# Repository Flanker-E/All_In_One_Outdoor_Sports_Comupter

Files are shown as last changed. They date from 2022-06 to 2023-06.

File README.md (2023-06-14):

# All-in-one Outdoor Sports Comupter







This is Team 15's final project git repository for EECS 473: Advanced Embedded Systems. 

The title of our project is **All-in-one Outdoor Sports Comupter**

The team members include: Zhewei Ye, Zheyuan Wu, Yuantao Bai, Yifan Yang, Yidong Zhen, Yuxin Wang.

## 🌟 Expo
Poster of the project

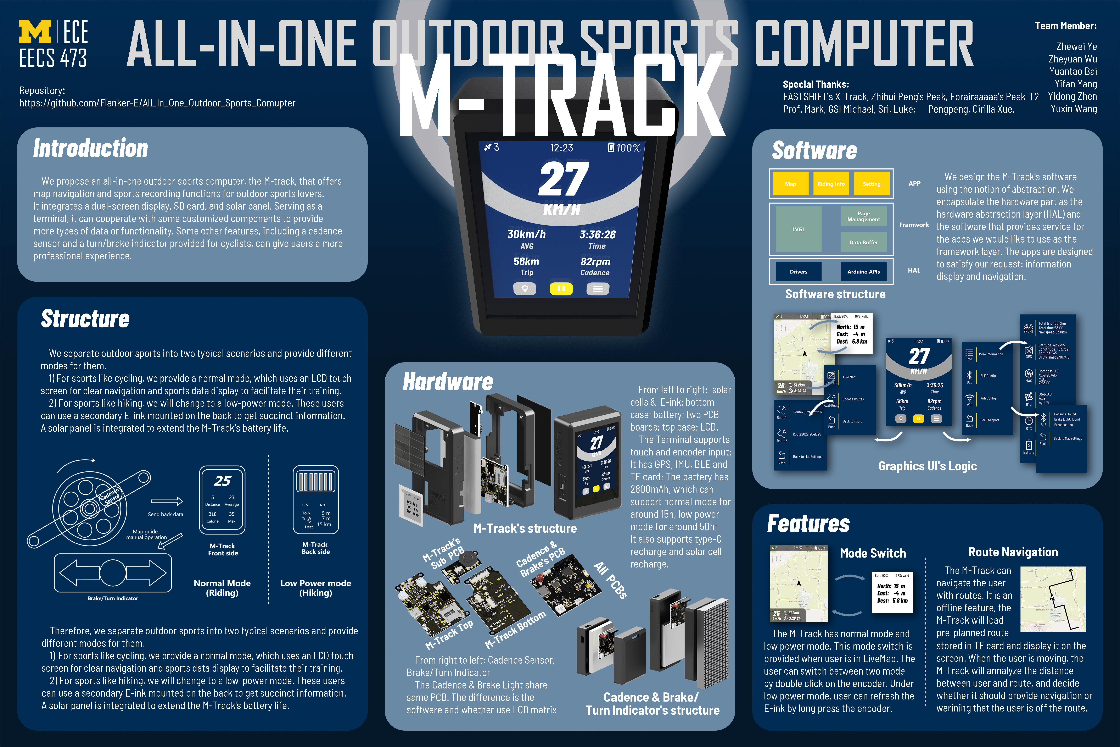
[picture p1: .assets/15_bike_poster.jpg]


## 🏅 Acknowledgement
Thanks for the great work: 
+ [**X-Track**](https://github.com/FASTSHIFT/X-TRACK)
+ [**Peak**](https://github.com/peng-zhihui/Peak)
+ [**Peak-T2**](https://gitee.com/forairaaaaa/peak-t2/tree/master/1.Hardware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)

## ⚙️ Firmware compile using PIO
Open project with Vscode, wait for PlatformIO to configure the project.  

### configure lvgl/lv_conf.h  
copy from lv_conf_template.h and change name to lv_conf.h  
line 15 change to -> #if 1 
line 52 change to -> #define LV_MEM_SIZE (38U * 1024U)          /*[bytes]*/  
line 88 change to -> #define LV_TICK_CUSTOM 1  
line 114 change to -> #define LV_SHADOW_CACHE_SIZE 50  
line 174 change to -> #define LV_USE_LOG 1  
line 210 change to -> #define LV_USE_ASSERT_STYLE 1  
line 245 change to -> #define LV_SPRINTF_USE_FLOAT 1  
line 306 change to -> #define LV_FONT_MONTSERRAT_10 1  
line 314 change to -> #define LV_FONT_MONTSERRAT_26 1  
line 348 change to -> #define LV_FONT_FMT_TXT_LARGE 1  
line 351 change to -> #define LV_USE_FONT_COMPRESSED 1  
line 526 change to -> #define LV_USE_THEME_BASIC 0  
line 529 change to -> #define LV_USE_THEME_MONO 0  

### using 7789V(PCB):  
#### configure TFT_eSPI/User_Setup.h  
uncomment line 45  
comment line 168-170  
comment line 205-210 and 223  
#### configure TFT_eSPI/User_Setup_select.h  
uncomment line 72 setup24_st7789.h  
#### configure TFT_eSPI/User_Setups/Setup24_ST7789.h  
uncomment line 10, enable TFT_RGB  
uncomment line 22-27, change TFT_CS to 9  
comment line 30-33  

### using IL9341(quick proto):   
#### configure TFT_eSPI/User_Setup.h  
comment line 168-170  
uncomment line 205-210 and 223  

## How to get simulator work on Windows
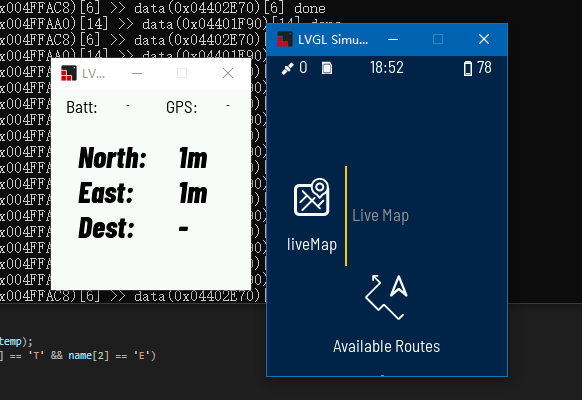
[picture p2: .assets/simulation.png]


Clone project.  
Open project with Vscode, wait for PlatformIO to configure the project.  
Download Visual Studio 2019.(can't work with 2022)  
Install module: C++ desktop(click on MSVC v142-VS 2019) and .NET desktop.  
Open the .sln file, select x86 Debug and run.  
Then the simulator should can work.  

## How to get simulator work on MacOS
todo 
some basic function don't work under Mac c++ env.

## Software Part Understanding
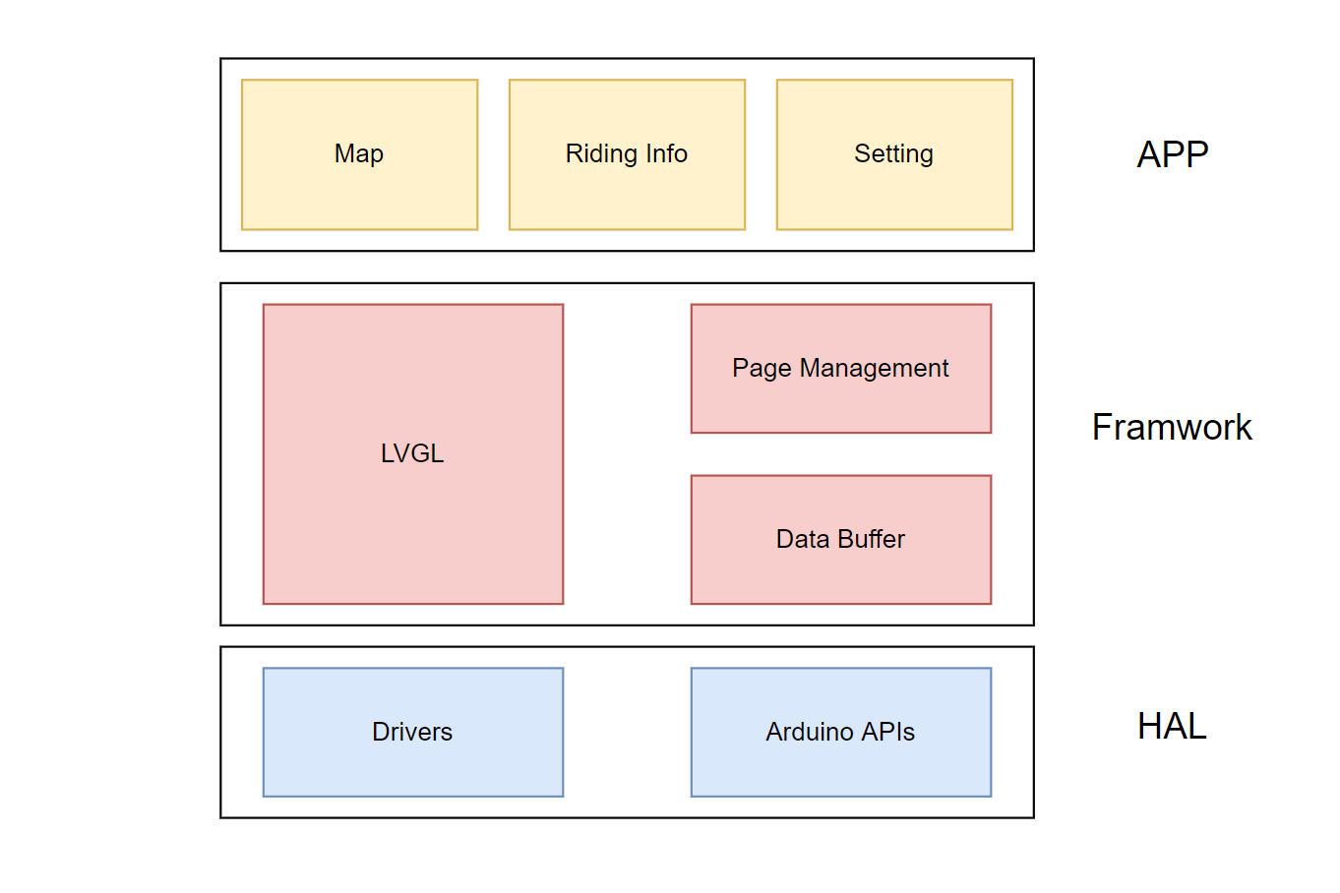
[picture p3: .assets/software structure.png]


### Software Init Pipeline
Setup:  
* HAL_init;  
    * buzz: thread(tailored in this project)  
*	Port_Init //LCD  
    * Tft object setup, binding with LVGL  
    * Create FreeRTOS task  
*	App_init  
    * Init data buffer, lv clear, init resourse, create apps, bind service  

Loop:  
*	HAL_update  

After that, the FreeRTOS will periodically call lv_handler, which gives lvgl heart beat.  
The software structure and lvgl outside of FreeRTOS will listen from input and periodic timers to do its job.  

### Software Structure (explaination on content)
#### FreeRTOS
* Task1: lvgl update  
* Task2: pending: HAL update 
* Task3: pending: switch between LCD and Eink 
plan : using state machine to control the shift between normal mode and low power mode.  
#### Data Buffer:
Namespace DataProc:  

class:  
Account:   
all account connect to one data center. Using an id to distinguish.   
Having a general pingpong buffer and a specified user data pointer.  
Using commit to get data and use publish to notify all subscriber with new data.  
Can data can be pull from subscriber.  
Timer’s utility? Cmd utility?  

DataCenter:  
Provide find specific account utility.  
Store accounts using account pool, which is a vector.  

Pingpong buffer:  

    void* buffer[2];
        volatile uint8_t writeIndex;
        volatile uint8_t readIndex;
        volatile uint8_t readAvaliable[2];
          
readidx=0 or 1. After read, set avai to 0.  
Write: can not be the same with read. Write to another slot and set its availability to 1.  

#### App
**AppFactory:** public inherited from PageFactory  
Provide createpage check function. Check whether “create a page named xx” is legal. Then return the page object  

**PageManager:** manage pages. Install, register, push&pop of page stack, page switch and the other stuff.  
Organized the page-switching logic!  
Install of page: init page, assign some information of this page.  
Register of page: assign PM’s this pointer, assign page name to itself (?), pushback in pagepool  

**Page stack and page pool:**  
Page stack is used to store the sequence of appearance of pages. Page pool is used to check whether a page is registered or not.  

The app will show after it is pushed into the stack by calling “SwitchTo”  
Switch to: detect and copy stash into the target page.  

The PM will raise StateUpdate to check the state and call corresponding functions in pages (state machine)  

**App uses the MVC framework:**  
[Basic concept reference](https://www.zhihu.com/question/27897315)  
[For detailed information and iOS ViewController: ](https://www.jianshu.com/p/caaa173071f3)  
[Difference from MVP: ](http://c.biancheng.net/view/7743.html) Then you will notice that there are differences in the definition of MVC.

Implemented functionality for page scheduling (lifecycle).

Porting: Add pages to the pool using "push" and go back to the previous page using "pop".

Ensure that the hardware is initialized to prevent SystemInfo from referencing a null pointer.

**Add other pages:**

Page: Interface functionality, including creation, display, loading, etc.

PageView: Implementation of functionalities such as creation, grouping, etc.

PageModel: Functionality for data interaction, such as reading data and updating.

onBtnClicked called by onEvent. onEvent is a callback function, which is attached to events by lv_obj_add_event_cb In onEvent

The onEvent will call different functions based on the event code.  

The information updates of map and dialplate are done by lv_timer  

#### Button and Lvgl
Encoder_Init provide: hardware interrupt when a pin changed, attach encoder with buttonEvent  
Bind encoder in the Encoder_Init only provide long press power off feature(disable encoder difference calc)  
Encoder_Update will call ButtonEvent’s EventMonitor, which judge the state of press. This can determin whether device should be power off.  

Lvgl determines press event using the encoder_read call-back function. It reads diff and state from encoder driver.  
#### Map
Using Microsoft Tiled map system: different scale, different image.   
Which uses scale number to calculate the crop of an image.  

Namespace page  
Class livemap :pagebase  

MapConv mapConv;  
TileConv tileConv;  

When things are being updated. Enter or outside from map?
Using lv_poly_line to record track line

Observation: the map will exit when button is pressed(before release)
#### Resource Pool
Import fonts, label images
## 🎬 Pictures and Documentation
+ Project Document: [**[PDF]**](https://github.com/Flanker-E/All_In_One_Outdoor_Sports_Comupter/blob/main/.assets/Team15_473F22_report.docx.pdf)

+ Route recording and navigation: Yellow is recorded route and blue is navigation route.

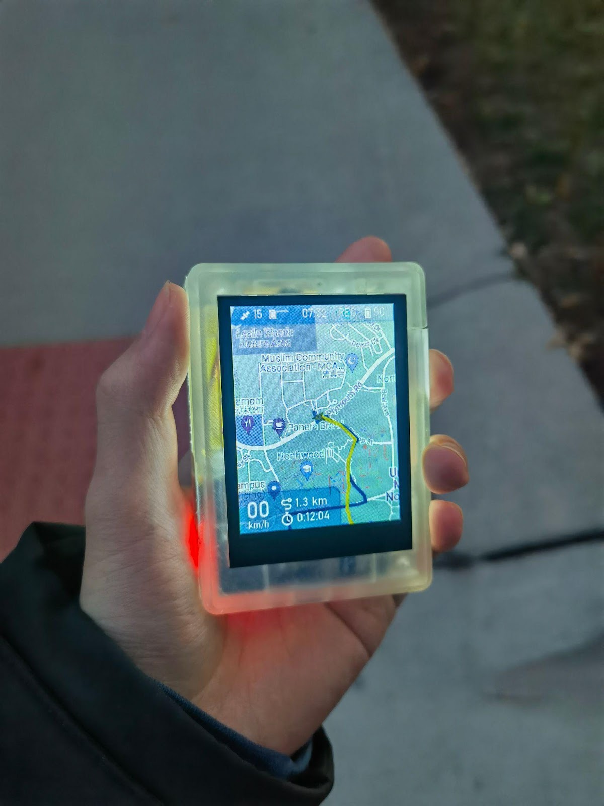
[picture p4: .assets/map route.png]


+ Front view
  
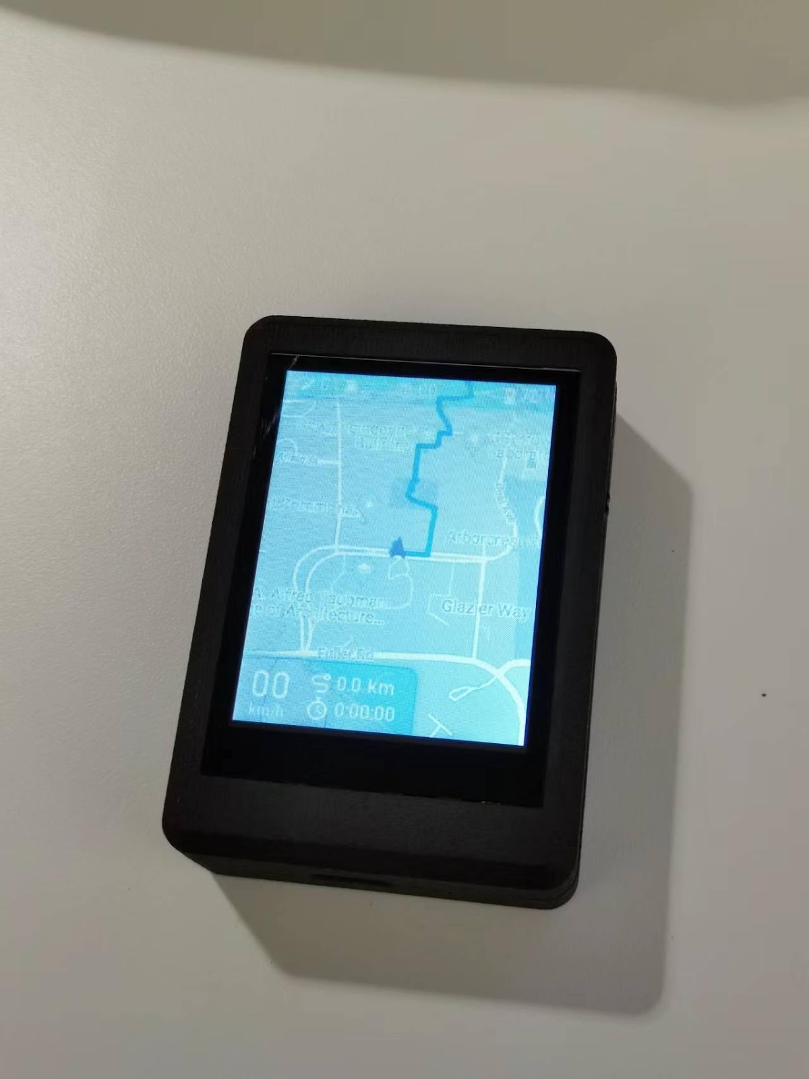
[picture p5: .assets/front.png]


+ Back view
  
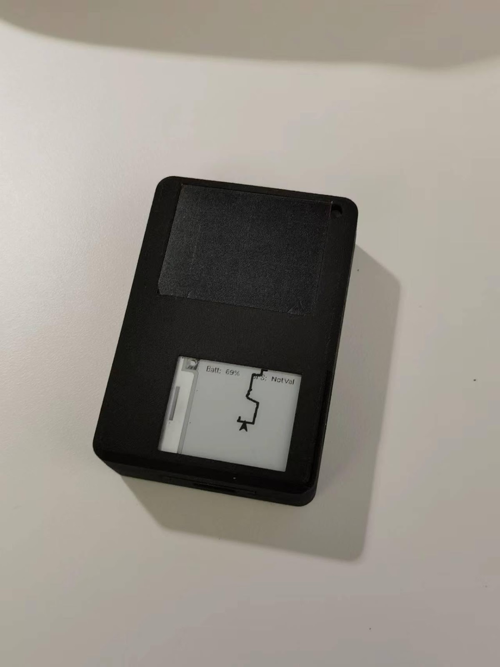
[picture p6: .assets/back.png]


+ Overall assembly rendering.

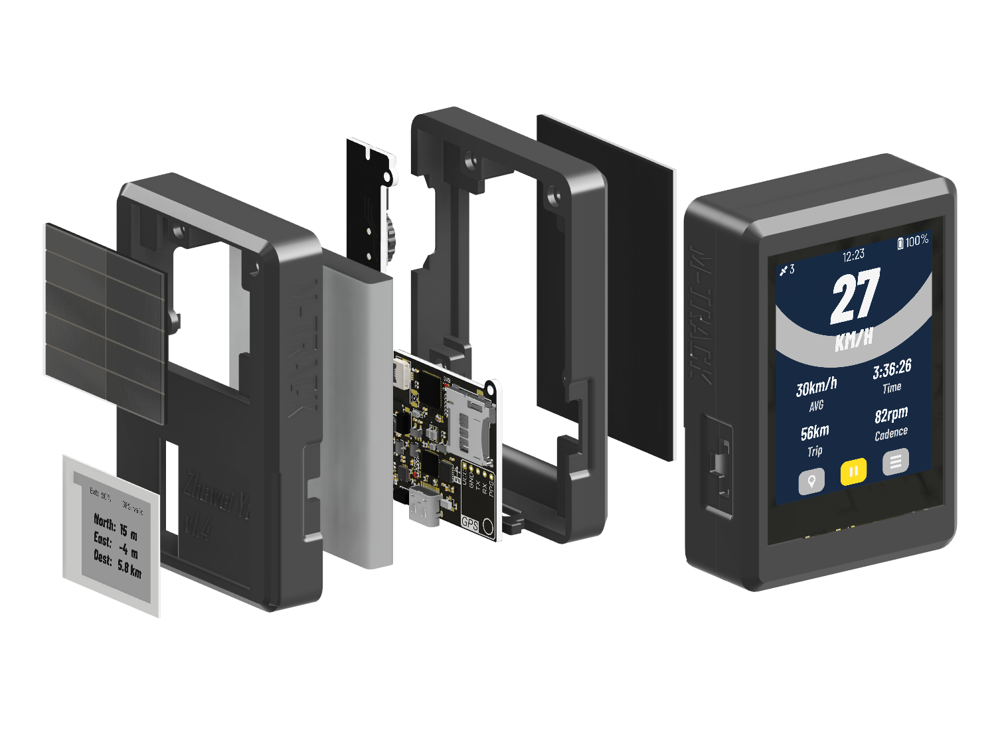
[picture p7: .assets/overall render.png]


+ inner rendering
  
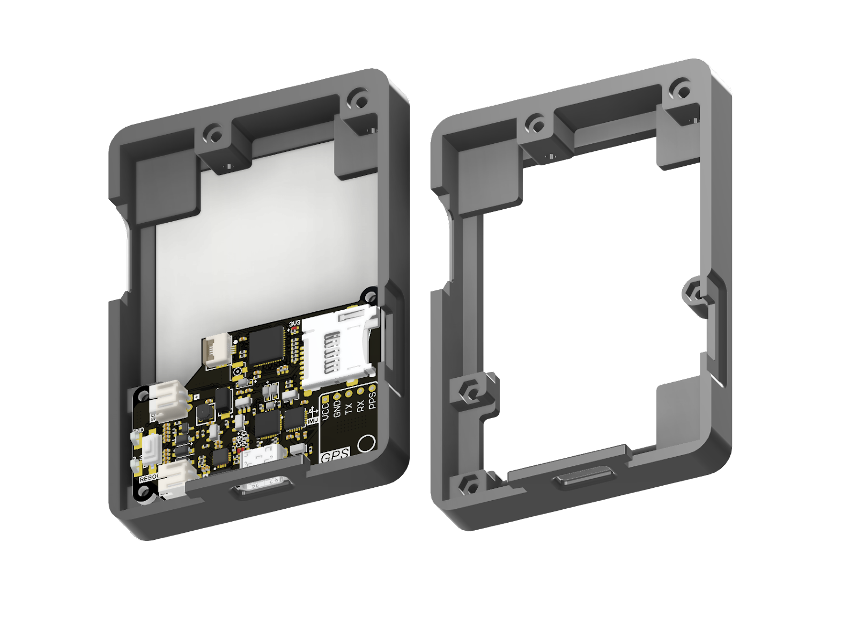
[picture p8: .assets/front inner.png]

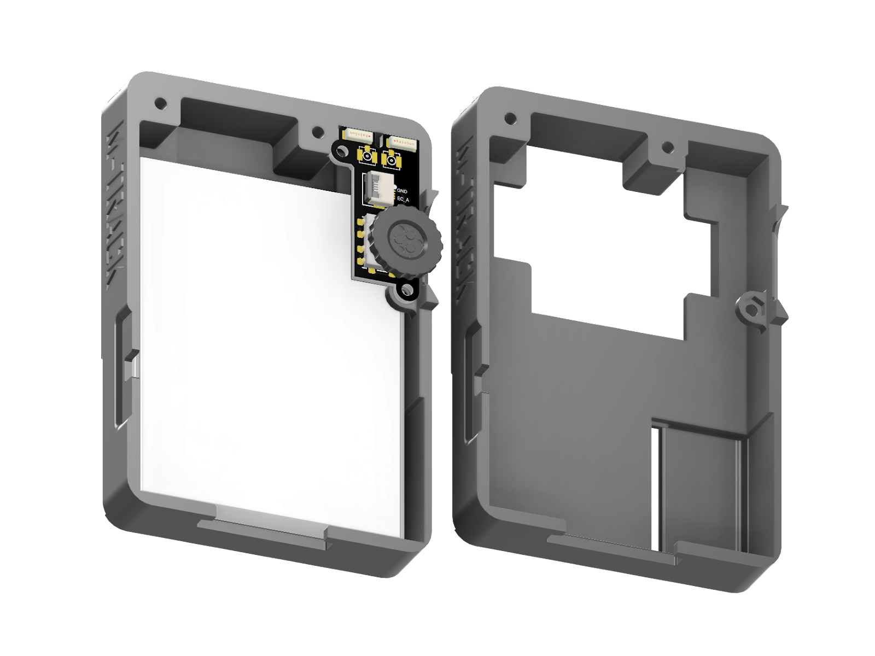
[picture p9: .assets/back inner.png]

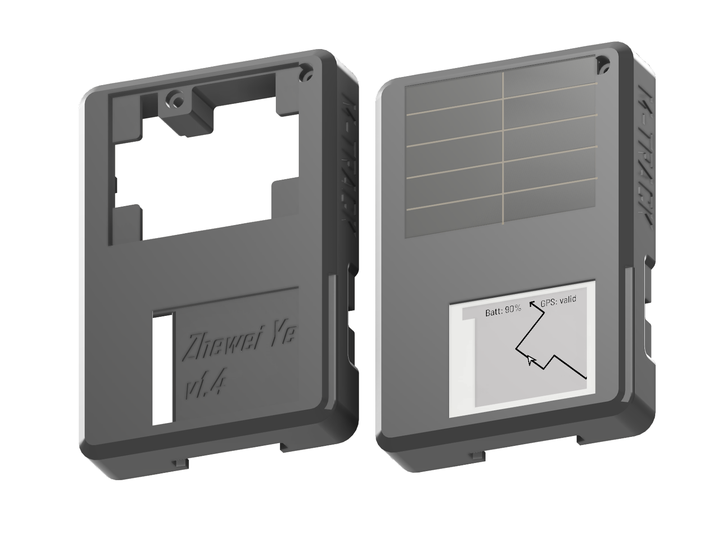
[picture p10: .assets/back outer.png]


+ PCB rendering and photo
  
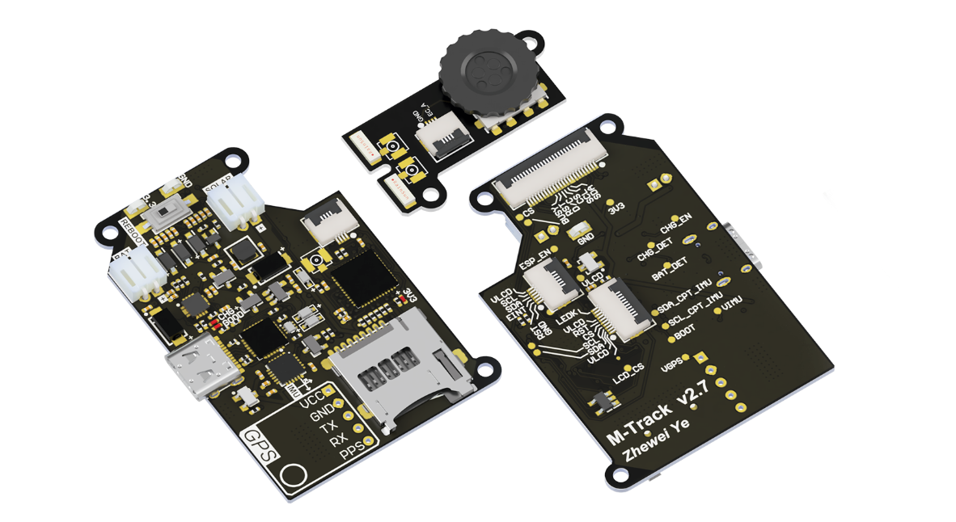
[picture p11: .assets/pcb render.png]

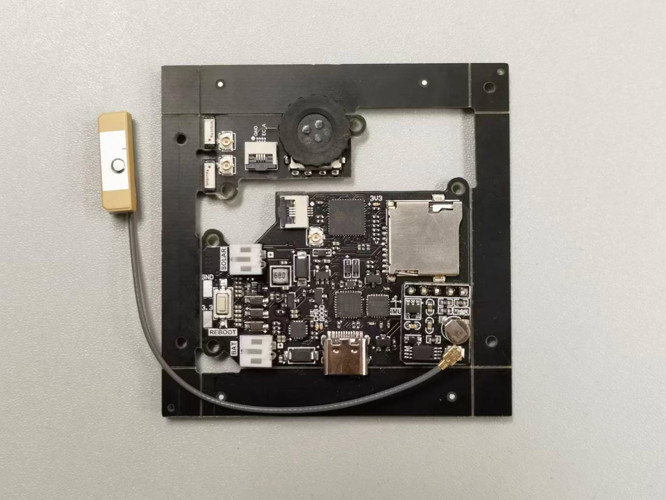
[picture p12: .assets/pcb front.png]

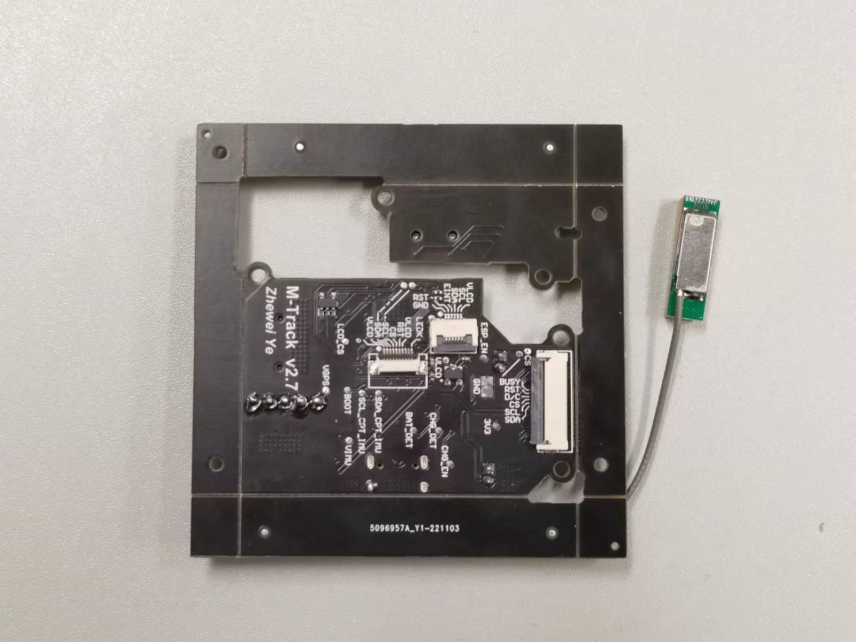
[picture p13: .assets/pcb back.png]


## 📫 Contact

+ Zhewei Ye, Email: yezhewei@umich.edu
+ Zheyuan Wu, Email: wuzy@umich.edu
+ Yuantao Bai, Email: yuantaob@umich.edu
+ Yifan Yang, Email: yifanyan@umich.edu
+ Yidong Zhen, Email: ydzhen@umich.edu
+ Yuxin Wang, Email: yuxinece@umich.edu
  
## 📌 Project Changelog
20220617 demo widges, run in FreeRTOS, with semaphor. Record before adding X-track page management and display port.  
20220624 touchpad on peak pages.  
20220626 sysinfo works. battery label update error.  
20220629 X-track pages, simulator, touchpad problem.  
20220928 sync using new machine.  
20221004 update hardware design.  
20221102 PCB v2.7 =>Fab  
20221110 case 3D modeling v1.3  
20221116 driver switch between LCD and EINK  
20221120 case 3D modeling v1.4, revision for PCB v2.7  
20221122 incorporate encoder and touch screen  
20221123 solved the switch between LCD and Eink  
20221127 adding settings page  
20221128 design settings items' icon  
20221202 fix encoder click logic  
20221205 poster stuff, tf card and map load  
20221206 time issure, positioning offset, route recording enable  
20221207 available route read and selection UI

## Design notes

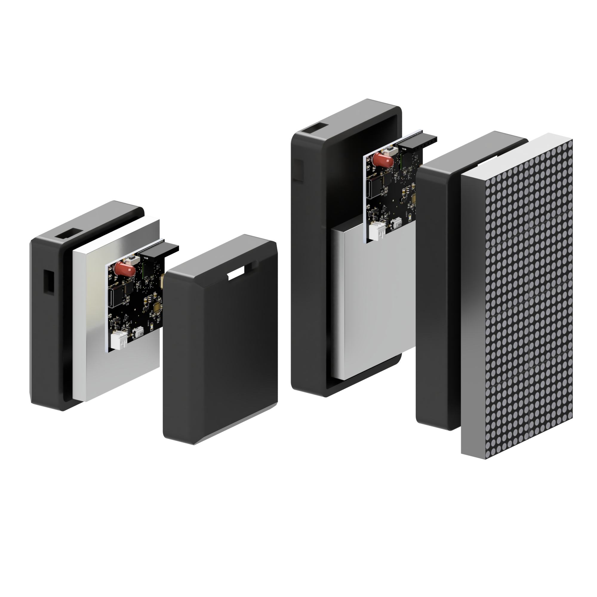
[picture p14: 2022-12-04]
Poster/Cadence_Brake.PNG

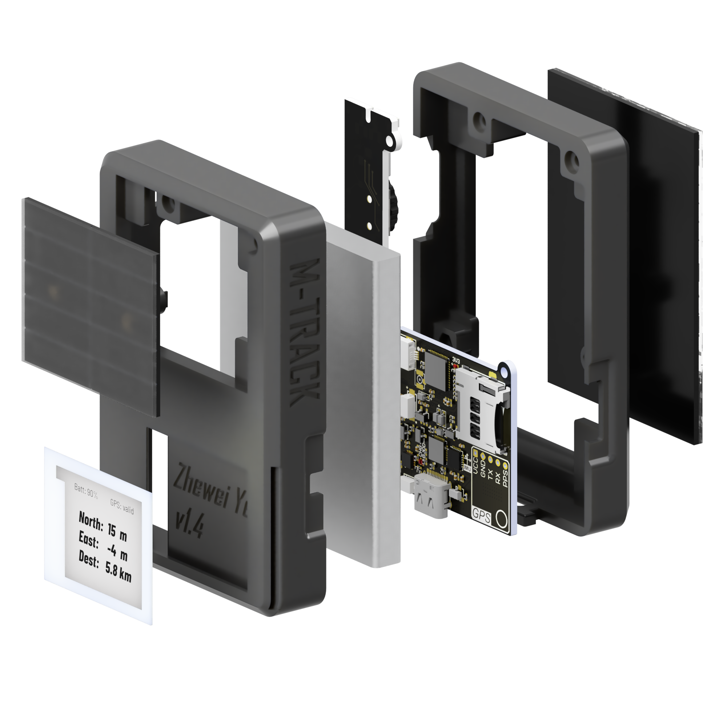
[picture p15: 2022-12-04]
Poster/M_TRACK_transpatent.png

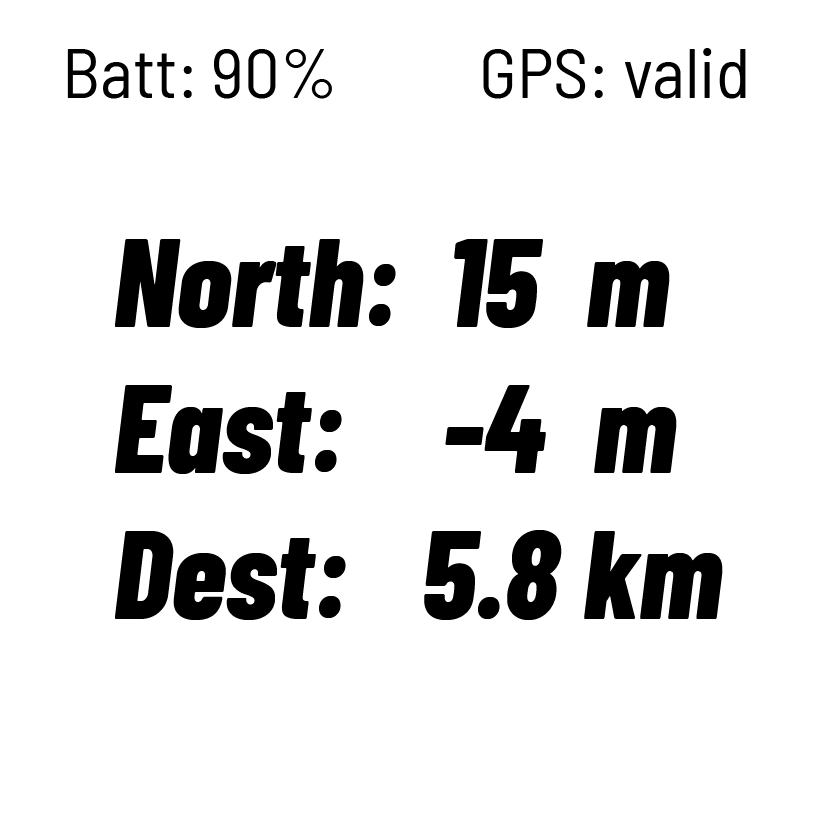
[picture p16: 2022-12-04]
Poster/E_ink.png

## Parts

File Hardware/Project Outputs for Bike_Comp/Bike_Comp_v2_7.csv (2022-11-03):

Comment | Description | Designator | Footprint | LibRef | Quantity
AN2051-245 | footprint: 2051 | A1, A2 | ANT-Rainsun-AN5120 | ANT-Rainsun-AP5120 | 2
ATGM336H Module | ATGM336H Module | AT1 | PCBComponent_1 | ATGM336H Module | 1
0.1uF | Capacitor | C1, C4, C6, C11, C13, C14, C16 | CAP_0402 | 电容-0402 | 7
10uF | Capacitor | C2, C5, C7, C8, C9, C17, C18, C19, C20 | CAP_0402 | 电容-0402 | 9
1uF | Capacitor | C10, C21, C25, C26, C27, C32 | CAP_0402 | 电容-0402 | 6
10nF | Capacitor | C12 | CAP_0402 | 电容-0402 | 1
2.2nF | Capacitor | C15 | CAP_0402 | 电容-0402 | 1
4.7uF | Capacitor | C22, C23, C24, C28, C29, C30, C31 | CAP_0402 | 电容-0402 | 7
FPC05006-09200 | 下接6p | CT1 | FPC0.5-WT-6P | CTP | 1
B5819W | 40V | D1, D2, D3 | SOD-323 | 二极管-5819W | 3
SK34A | GOOD_ARK Schottky Diode | D4, D6 | SMA | SK34AFL-TP | 2
LTST-C281KGKT | GREEN_LED | D5, D8 | LED_0402_RED | LED_0402 | 2
16-213/SDRC/S530-A3/TR8 | RED_LED | D7 | LED_0402_RED | LED_0402 | 1
MBR0530 | Diode | D9, D10, D11 | SOD3716X135N | MBR0530 | 3
FPC05024-17205 | 上接24p | EINK1 | FPC0.5-WT-24P | EINK | 1
BQ24074RGTR | Integrated Circuit | IC1 | QFN50P300X300X100-17N-D | BQ24074RGTR | 1
74LVC1G04W5-7 | Integrated Circuit | IC2 | SOT95P285X140-5N | 74LVC1G04W5-7 | 1
IPEX-4 | Socket, Plug | J1, J2, P2 | COAXIAL/SMD/CON/V/I-PEX/W08-5801 | Socket, Plug | 3
68uH ±20% | Magnetic-Core Inductor | L1 | SWPA3015 | Inductor Iron | 1
0.5-10P上接 | 上接10p | LC1 | FPC0.5-WT-10P | LCD | 1
BAT_CON | PH2.0-2P-LT | P1 | PH2.0-W-2P | Header 2 | 1
C191195 | Header, 4-Pin | P3, P4 | FPC0.5-WT-4P | Header 4 | 2
SOLAR_CON | PH2.0-2P-LT | P6 | PH2.0-W-2P | Header 2 | 1
AO3401A | P-MOS | Q1, Q6, Q8 | SOT23-3 | AO3401A | 3
AO3400A | N-MOS | Q2, Q4 | SOT23-3 | AO3400A | 2
EMX1T2R |  | Q3 | SOT563-6 | BC847BVC-7 | 1
Si1308EDL-T1-GE3 | MOSFET (N-Channel) | Q9 | SOT65P210X110-3N | Si1308EDL-T1-GE3 | 1
10K | Resistor | R1, R8, R11, R13, R17, R18, R19, R20, R21, R22, R23, R25, R26, R27, R32, R34, R35, R36 | RES_0402 | 电阻-0402 | 18
100K | Resistor | R2, R4, R28, R30 | RES_0402 | 电阻-0402 | 4
20K | Resistor | R3, R7 | RES_0402 | 电阻-0402 | 2
0R | Resistor | R5, R24, R38, R39 | RES_0402 | 电阻-0402 | 4
200R | Resistor | R6 | RES_0402 | 电阻-0402 | 1
12K | Resistor | R9, R12 | RES_0402 | 电阻-0402 | 2
1K | Resistor | R10, R31 | RES_0402 | 电阻-0402 | 2
5.1K | Resistor | R14, R16 | RES_0402 | 电阻-0402 | 2
10R | Resistor | R15 | RES_0402 | 电阻-0402 | 1
TSA363G25-250B | Single-Pole, Single-Throw Switch | S1 | SW SMD-3*6*2.5 | SW-SPST | 1
SIQ-02FVS3 | Rotary Encoder | SW1 | SIQ-02FVS3 | Rotary Encoder | 1
TF-012D | 8脚自弹 | TF1 | TF-SOCKET | TF卡座 | 1
TP |  | TP1, TP3, TP10 | TP_SMD | TP | 3
TP |  | TP2, TP4, TP5, TP6, TP7, TP8, TP9, TP12, TP14, TP15, TP16, TP17, TP18, TP19, TP20, TP22, TP23 | TEST 1 | TP | 17
ME6215C33M5G | LDO module changed, BYPASS now is NC | U1 | SOT23-5 | LP2992 | 1
CP2102 | USB转TTL | U2 | QFN-28 | CP2102 | 1
ESP32-PICO-D4 |  | U4 | QFN-48_7X7 | ESP32-PICO | 1
MPU6050 | 六轴传感器 | U5 | QFN-24 | MPU6050 | 1
TYPE-611-T3 | 16pin | USB1 | Type-C-TOP | USB-Type-C-TOP | 1

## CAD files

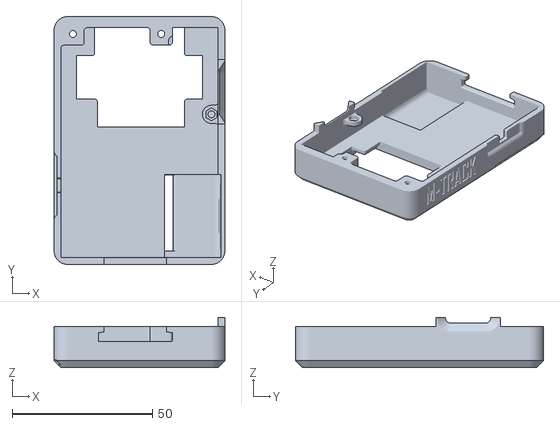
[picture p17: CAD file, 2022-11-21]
Model/M_Track_back_v1_4.stl
61.0 x 88.5 x 18.0

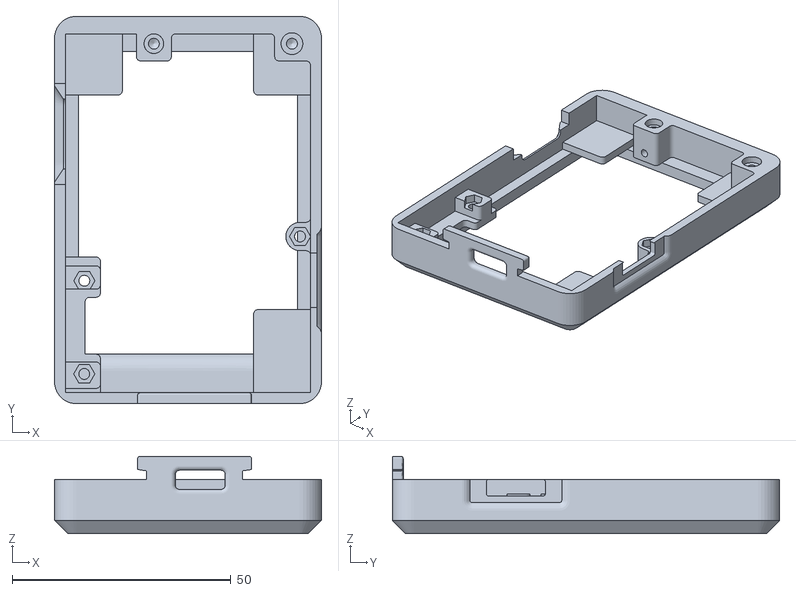
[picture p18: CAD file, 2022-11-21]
Model/M_Track_front_v1_4.stl
61.0 x 88.5 x 17.6

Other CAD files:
Model/back_v1_4.f3d
Model/front_v1_4.f3d

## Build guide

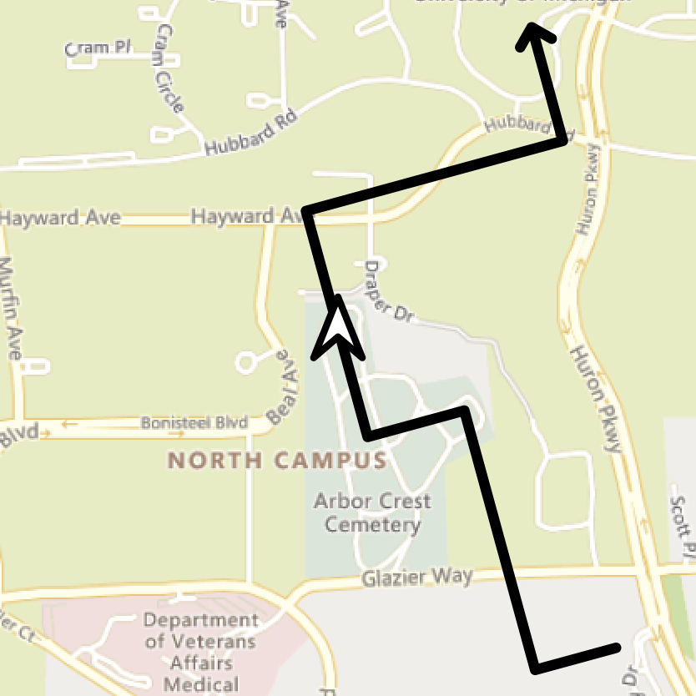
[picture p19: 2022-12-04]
Poster/RouteGuide_ 1.png

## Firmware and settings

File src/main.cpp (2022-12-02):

// #include <lv_demos.h>
// #include <TFT_eSPI.h>
#include "Port/Display.h"
#include "HAL/HAL.h"
#include "App/App.h"


// #include "TouchScreen.h"

void setup()
{
  //  File f = SPIFFS.open(CALIBRATION_FILE, "r");
    // Serial.begin( 115200 ); /* prepare for possible serial debug */

    // String LVGL_Arduino = "Hello Arduino! ";
    // LVGL_Arduino += String('V') + lv_version_major() + "." + lv_version_minor() + "." + lv_version_patch();

    // Serial.println( LVGL_Arduino );
    // Serial.println( "I am LVGL_Arduino" );


    HAL::HAL_Init();
    Serial.println( "HAL Init" );
    Port_Init();
    // To_Eink_Port();

    // To_LCD_Port();
    // Serial.printf( "maintest:%d\n",test );
    Serial.println( "Port Init" );

    App_Init();

    Serial.println( "Setup done" );
}

void loop()
{
  HAL::HAL_Update();
    // xTaskNotifyGive(handleTaskLvgl);
    // lv_timer_handler(); /* let the GUI do its work */
    // lv_tick_inc(5);
    delay( 20 );
}


  
    /*
  Example animated analogue meters using a ILI9341 TFT LCD screen

  Needs Font 2 (also Font 4 if using large scale label)

  Make sure all the display driver and pin comnenctions are correct by
  editting the User_Setup.h file in the TFT_eSPI library folder.

  #########################################################################
  ###### DON'T FORGET TO UPDATE THE User_Setup.h FILE IN THE LIBRARY ######
  #########################################################################
*/
// #include "FS.h"

// #include <SPI.h>
// #include <TFT_eSPI.h>      // Hardware-specific library

// TFT_eSPI tft = TFT_eSPI(); // Invoke custom library

// // This is the file name used to store the calibration data
// // You can change this to create new calibration files.
// // The SPIFFS file name must start with "/".
// #define CALIBRATION_FILE "/TouchCalData1"

// // Set REPEAT_CAL to true instead of false to run calibration
// // again, otherwise it will only be done once.
// // Repeat calibration if you change the screen rotation.
// #define REPEAT_CAL false

// // Keypad start position, key sizes and spacing
// #define KEY_X 40 // Centre of key
// #define KEY_Y 96
// #define KEY_W 62 // Width and height
// #define KEY_H 30
// #define KEY_SPACING_X 18 // X and Y gap
// #define KEY_SPACING_Y 20
// #define KEY_TEXTSIZE 1   // Font size multiplier

// // Using two fonts since numbers are nice when bold
// #define LABEL1_FONT &FreeSansOblique12pt7b // Key label font 1
// #define LABEL2_FONT &FreeSansBold12pt7b    // Key label font 2

// // Numeric display box size and location
// #define DISP_X 1
// #define DISP_Y 10
// #define DISP_W 238
// #define DISP_H 50
// #define DISP_TSIZE 3
// #define DISP_TCOLOR TFT_CYAN

// // Number length, buffer for storing it and character index
// #define NUM_LEN 12
// char numberBuffer[NUM_LEN + 1] = "";
// uint8_t numberIndex = 0;

// // We have a status line for messages
// #define STATUS_X 120 // Centred on this
// #define STATUS_Y 65

// // Create 15 keys for the keypad
// char keyLabel[15][5] = {"New", "Del", "Send", "1", "2", "3", "4", "5", "6", "7", "8", "9", ".", "0", "#" };
// uint16_t keyColor[15] = {TFT_RED, TFT_DARKGREY, TFT_DARKGREEN,
//                          TFT_BLUE, TFT_BLUE, TFT_BLUE,
//                          TFT_BLUE, TFT_BLUE, TFT_BLUE,
//                          TFT_BLUE, TFT_BLUE, TFT_BLUE,
//                          TFT_BLUE, TFT_BLUE, TFT_BLUE
//                         };

// // Invoke the TFT_eSPI button class and create all the button objects
// TFT_eSPI_Button key[15];

// //------------------------------------------------------------------------------------------
// //------------------------------------------------------------------------------------------

// void drawKeypad()
// {
//   // Draw the keys
//   for (uint8_t row = 0; row < 5; row++) {
//     for (uint8_t col = 0; col < 3; col++) {
//       uint8_t b = col + row * 3;

//       if (b < 3) tft.setFreeFont(LABEL1_FONT);
//       else tft.setFreeFont(LABEL2_FONT);

//       key[b].initButton(&tft, KEY_X + col * (KEY_W + KEY_SPACING_X),
//                         KEY_Y + row * (KEY_H + KEY_SPACING_Y), // x, y, w, h, outline, fill, text
//                         KEY_W, KEY_H, TFT_WHITE, keyColor[b], TFT_WHITE,
//                         keyLabel[b], KEY_TEXTSIZE);
//       key[b].drawButton();
//     }
//   }
// }

// //------------------------------------------------------------------------------------------

// void touch_calibrate()
// {
//   uint16_t calData[5];
//   uint8_t calDataOK = 0;

//   // check file system exists
//   if (!SPIFFS.begin()) {
//     Serial.println("Formating file system");
//     SPIFFS.format();
//     SPIFFS.begin();
//   }

//   // check if calibration file exists and size is correct
//   if (SPIFFS.exists(CALIBRATION_FILE)) {
//     if (REPEAT_CAL)
//     {
//       // Delete if we want to re-calibrate
//       SPIFFS.remove(CALIBRATION_FILE);
//     }
//     else
//     {
//       File f = SPIFFS.open(CALIBRATION_FILE, "r");
//       if (f) {
//         if (f.readBytes((char *)calData, 14) == 14)
//           calDataOK = 1;
//         f.close();
//       }
//     }
//   }

//   if (calDataOK && !REPEAT_CAL) {
//     // calibration data valid
//     tft.setTouch(calData);
//   } else {
//     // data not valid so recalibrate
//     tft.fillScreen(TFT_BLACK);
//     tft.setCursor(20, 0);
//     tft.setTextFont(2);
//     tft.setTextSize(1);
//     tft.setTextColor(TFT_WHITE, TFT_BLACK);

//     tft.println("Touch corners as indicated");

//     tft.setTextFont(1);
//     tft.println();

//     if (REPEAT_CAL) {
//       tft.setTextColor(TFT_RED, TFT_BLACK);
//       tft.println("Set REPEAT_CAL to false to stop this running again!");
//     }

//     tft.calibrateTouch(calData, TFT_MAGENTA, TFT_BLACK, 15);

//     tft.setTextColor(TFT_GREEN, TFT_BLACK);
//     tft.println("Calibration complete!");

//     // store data
//     File f = SPIFFS.open(CALIBRATION_FILE, "w");
//     if (f) {
//       f.write((const unsigned char *)calData, 14);
//       f.close();
//     }
//   }
// }

// //------------------------------------------------------------------------------------------

// // Print something in the mini status bar
// void status(const char *msg) {
//   tft.setTextPadding(240);
//   //tft.setCursor(STATUS_X, STATUS_Y);
//   tft.setTextColor(TFT_WHITE, TFT_DARKGREY);
//   tft.setTextFont(0);
//   tft.setTextDatum(TC_DATUM);
//   tft.setTextSize(1);
//   tft.drawString(msg, STATUS_X, STATUS_Y);
// }

// void setup() {
//   // Use serial port
//   Serial.begin(115200);

//   // Initialise the TFT screen
//   tft.init();

//   // Set the rotation before we calibrate
//   tft.setRotation(0);

//   // Calibrate the touch screen and retrieve the scaling factors
//   touch_calibrate();

//   // Clear the screen
//   tft.fillScreen(TFT_BLACK);

//   // Draw keypad background
//   tft.fillRect(0, 0, 240, 320, TFT_DARKGREY);

//   // Draw number display area and frame
//   tft.fillRect(DISP_X, DISP_Y, DISP_W, DISP_H, TFT_BLACK);
//   tft.drawRect(DISP_X, DISP_Y, DISP_W, DISP_H, TFT_WHITE);

//   // Draw keypad
//   drawKeypad();
// }

// //------------------------------------------------------------------------------------------

// void loop(void) {
//   uint16_t t_x = 0, t_y = 0; // To store the touch coordinates

//   // Pressed will be set true is there is a valid touch on the screen
//   bool pressed = tft.getTouch(&t_x, &t_y);

//   // / Check if any key coordinate boxes contain the touch coordinates
//   for (uint8_t b = 0; b < 15; b++) {
//     if (pressed && key[b].contains(t_x, t_y)) {
//       key[b].press(true);  // tell the button it is pressed
//     } else {
//       key[b].press(false);  // tell the button it is NOT pressed
//     }
//   }

//   // Check if any key has changed state
//   for (uint8_t b = 0; b < 15; b++) {

//     if (b < 3) tft.setFreeFont(LABEL1_FONT);
//     else tft.setFreeFont(LABEL2_FONT);

//     if (key[b].justReleased()) key[b].drawButton();     // draw normal

//     if (key[b].justPressed()) {
//       key[b].drawButton(true);  // draw invert

//       // if a numberpad button, append the relevant # to the numberBuffer
//       if (b >= 3) {
//         if (numberIndex < NUM_LEN) {
//           numberBuffer[numberIndex] = keyLabel[b][0];
//           numberIndex++;
//           numberBuffer[numberIndex] = 0; // zero terminate
//         }
//         status(""); // Clear the old status
//       }

//       // Del button, so delete last char
//       if (b == 1) {
//         numberBuffer[numberIndex] = 0;
//         if (numberIndex > 0) {
//           numberIndex--;
//           numberBuffer[numberIndex] = 0;//' ';
//         }
//         status(""); // Clear the old status
//       }

//       if (b == 2) {
//         status("Sent value to serial port");
//         Serial.println(numberBuffer);
//       }
//       // we dont really check that the text field makes sense
//       // just try to call
//       if (b == 0) {
//         status("Value cleared");
//         numberIndex = 0; // Reset index to 0
//         numberBuffer[numberIndex] = 0; // Place null in buffer
//       }

//       // Update the number display field
//       tft.setTextDatum(TL_DATUM);        // Use top left corner as text coord datum
//       tft.setFreeFont(&FreeSans18pt7b);  // Choose a nicefont that fits box
//       tft.setTextColor(DISP_TCOLOR);     // Set the font colour

//       // Draw the string, the value returned is the width in pixels
//       int xwidth = tft.drawString(numberBuffer, DISP_X + 4, DISP_Y + 12);

//       // Now cover up the rest of the line up by drawing a black rectangle.  No flicker this way
//       // but it will not work with italic or oblique fonts due to character overlap.
//       tft.fillRect(DISP_X + 4 + xwidth, DISP_Y + 1, DISP_W - xwidth - 5, DISP_H - 2, TFT_BLACK);

//       delay(10); // UI debouncing
//     }
//   }
// }


/*
    Video: https://www.youtube.com/watch?v=oCMOYS71NIU
    Based on Neil Kolban example for IDF: https://github.com/nkolban/esp32-snippets/blob/master/cpp_utils/tests/BLE%20Tests/SampleNotify.cpp
    Ported to Arduino ESP32 by Evandro Copercini
   Create a BLE server that, once we receive a connection, will send periodic notifications.
   创建一个BLE服务器，一旦我们收到连接，将会周期性发送通知
   T使用步骤：
   1. 创建一个 BLE Server
   2. 创建一个 BLE Service
   3. 创建一个 BLE Characteristic
   4. 创建一个 BLE Descriptor
   5. 开始服务
   6. 开始广播
*/
// #include <Arduino.h>
// #include <BLEDevice.h>
// #include <BLEServer.h>
// #include <BLEUtils.h>
// #include <BLE2902.h>
// // #include "common.h"

// uint8_t txValue = 0;
// BLEServer *pServer = NULL;                   //BLEServer指针 pServer
// BLECharacteristic *pTxCharacteristic = NULL; //BLECharacteristic指针 pTxCharacteristic
// bool deviceConnected = false;                //本次连接状态
// bool oldDeviceConnected = false;             //上次连接状态

// // See the following for generating UUIDs: https://www.uuidgenerator.net/
// #define SERVICE_UUID "3edbfa93-d64b-43c0-9d3c-e7388d43cd2f" // UART service UUID
// #define CHARACTERISTIC_UUID_RX "b42546cf-eac9-4b06-9377-17d71468e337"
// #define CHARACTERISTIC_UUID_TX "89b8d897-1faa-4c1d-9237-2aaf3584484c"

// class MyServerCallbacks : public BLEServerCallbacks
// {
//     void onConnect(BLEServer *pServer)
//     {
//         deviceConnected = true;
//     };

//     void onDisconnect(BLEServer *pServer)
//     {
//         deviceConnected = false;
//     }
// };

// class MyCallbacks : public BLECharacteristicCallbacks
// {
//     void onWrite(BLECharacteristic *pCharacteristic)
//     {
//         std::string rxValue = pCharacteristic->getValue(); //接收信息

//         if (rxValue.length() > 0)
//         { //向串口输出收到的值
//             Serial.print("RX: ");
//             for (int i = 0; i < rxValue.length(); i++)
//                 Serial.print(rxValue[i]);
//             Serial.println();
//         }
//     }
// };

// void setup()
// {
//     Serial.begin(115200);

//     // 创建一个 BLE 设备
//     BLEDevice::init("UART_BLE");

//     // 创建一个 BLE 服务
//     pServer = BLEDevice::createServer();
//     pServer->setCallbacks(new MyServerCallbacks()); //设置回调
//     BLEService *pService = pServer->createService(SERVICE_UUID);

//     // 创建一个 BLE 特征
//     pTxCharacteristic = pService->createCharacteristic(CHARACTERISTIC_UUID_TX, BLECharacteristic::PROPERTY_NOTIFY);
//     pTxCharacteristic->addDescriptor(new BLE2902());
//     BLECharacteristic *pRxCharacteristic = pService->createCharacteristic(CHARACTERISTIC_UUID_RX, BLECharacteristic::PROPERTY_WRITE);
//     pRxCharacteristic->setCallbacks(new MyCallbacks()); //设置回调

//     pService->start();                  // 开始服务
//     pServer->getAdvertising()->start(); // 开始广播
//     Serial.println(" waiting for connection... ");
// }

// void loop()
// {
//     // deviceConnected 已连接
//     if (deviceConnected)
//     {
//         pTxCharacteristic->setValue(&txValue, 1); // 设置要发送的值为1
//         pTxCharacteristic->notify();              // 广播
//         txValue++;                                // 指针地址自加1
//         delay(2000);                              // 如果有太多包要发送，蓝牙会堵塞
//     }

//     // disconnecting  断开连接
//     if (!deviceConnected && oldDeviceConnected)
//     {
//         delay(500);                  // 留时间给蓝牙缓冲
//         pServer->startAdvertising(); // 重新广播
//         Serial.println(" begin broadcast ");
//         oldDeviceConnected = deviceConnected;
//     }

//     // connecting  正在连接
//     if (deviceConnected && !oldDeviceConnected)
//     {
//         // do stuff here on connecting
//         oldDeviceConnected = deviceConnected;
//     }
// }

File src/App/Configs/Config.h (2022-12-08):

#ifndef __CONFIG_H
#define __CONFIG_H

/*=========================
   Application configuration
 *=========================*/

#define CONFIG_SYSTEM_SAVE_FILE_PATH          "/SystemSave.json"
#define CONFIG_SYSTEM_SAVE_FILE_BACKUP_PATH   "/.SystemSaveBackup.json"
#define CONFIG_SYSTEM_LANGUAGE_DEFAULT        "en-GB"//{'e','n','-','G','B'}
#define CONFIG_SYSTEM_TIME_ZONE_DEFAULT      (-5) // GMT- 5, Ann Arbor
#define CONFIG_SYSTEM_SOUND_ENABLE_DEFAULT    false

#define CONFIG_WEIGHT_DEFAULT                 70 // kg

#define CONFIG_GPS_REFR_PERIOD                1000 // ms
#define CONFIG_GPS_LONGITUDE_DEFAULT          -83.7161   //Ann Arbor duder
#define CONFIG_GPS_LATITUDE_DEFAULT           42.2905
#define CONFIG_GPS_LONGTITUDE_OFFSET          -0.041925
#define CONFIG_GPS_LATITUDE_OFFSET            0.002818

#define CONFIG_MAP_DOUBLE_CLICKED_DELAY       700
#define CONFIG_MAP_LONG_PRESSED_TIME          1000

#define CONFIG_TRACK_FILTER_OFFSET_THRESHOLD  2 // pixel
#define CONFIG_TRACK_RECORD_FILE_DIR_NAME     "Track"

#define CONFIG_ROUTE_FILE_DIR_NAME            "/Route"

#define CONFIG_MAP_USE_WGS84_DEFAULT          false

//#define CONFIG_MAP_DIR_PATH                   {'/','M','A','P'}//"/MAP"
#define CONFIG_MAP_DIR_PATH_DEFAULT           "/MAP"

#define CONFIG_MAP_EXT_NAME_DEFAULT           "bin"

#define CONFIG_ARROW_THEME_DEFAULT            "default"

#define CONFIG_LIVE_MAP_LEVEL_DEFAULT         16
#define CONFIG_LIVE_MAP_VIEW_WIDTH            LV_HOR_RES
#define CONFIG_LIVE_MAP_VIEW_HEIGHT           LV_VER_RES

// color config
#define UMICH_COLOR_MAIZE                     lv_color_hex(0xffcb05)
#define UMICH_COLOR_BLUE                      lv_color_hex(0x00274c)
#define UMICH_COLOR_WHITE                     lv_color_hex(0xffffff)

// #define COLOR_BACKGROUND                      lv_color_black()
// #define COLOR_FOCUS                           lv_color_hex(0xff931e)
// #define COLOR_TEXT                            lv_color_white()
// #define COLOR_DIM_TEXT                        lv_color_hex(0xb3b3b3)
// #define COLOR_UNFOCUS                         lv_color_hex(0x666666)
// #define COLOR_PRESSED                         lv_color_hex(0xbbbbbb)

#define COLOR_BACKGROUND                      UMICH_COLOR_BLUE
#define COLOR_FOCUS                           UMICH_COLOR_MAIZE

// #define COLOR_BACKGROUND                      lv_color_black()
// #define COLOR_FOCUS                           UMICH_COLOR_BLUE
#define COLOR_TEXT                            UMICH_COLOR_WHITE
#define COLOR_DIM_TEXT                        lv_color_hex(0x939393)
#define COLOR_UNFOCUS                         COLOR_DIM_TEXT
#define COLOR_PRESSED                         COLOR_DIM_TEXT

/* Simulator */
#define CONFIG_TRACK_VIRTUAL_GPX_FILE_PATH    "S:/TRK_20210801_203324.gpx"

/*=========================
   Hardware Configuration
 *=========================*/

/* Sensors */
#define CONFIG_SENSOR_ENABLE        1

#if CONFIG_SENSOR_ENABLE
#  define CONFIG_SENSOR_IMU_ENABLE  1
#  define CONFIG_SENSOR_MAG_ENABLE  1
#endif

#define NULL_PIN                    PD0

/* Screen */
#define CONFIG_SCREEN_CS_PIN        9
#define CONFIG_SCREEN_DC_PIN        2
#define CONFIG_SCREEN_RST_PIN       4
#define CONFIG_SCREEN_SCK_PIN       18
#define CONFIG_SCREEN_MOSI_PIN      23
#define CONFIG_SCREEN_BLK_PIN       12

#define CONFIG_SCREEN_HOR_RES       240//240
#define CONFIG_SCREEN_VER_RES       320
#define CONFIG_SCREEN_BUFFER_SIZE   (CONFIG_SCREEN_HOR_RES * CONFIG_SCREEN_VER_RES /2)

/* Battery */
#define CONFIG_BAT_DET_PIN          37
#define CONFIG_BAT_CHG_DET_PIN      38

/* Buzzer */
#define CONFIG_BUZZ_PIN             25
#define CONFIG_BUZZ_CHANNEL         2
#define CONFIG_SOUND_ENABLE_DEFAULT false

/* GPS */
#define CONFIG_GPS_SERIAL           Serial2
#define CONFIG_GPS_USE_TRANSPARENT  0
#define CONFIG_GPS_BUF_OVERLOAD_CHK 0
#define CONFIG_GPS_TX_PIN           36
#define CONFIG_GPS_RX_PIN           19

/* IMU */
#define CONFIG_IMU_INT1_PIN         32
#define CONFIG_IMU_INT2_PIN         33

/* I2C */
#define CONFIG_MCU_SDA_PIN          32
#define CONFIG_MCU_SCL_PIN          33

/* Encoder */
#define CONFIG_ENCODER_B_PIN        34
#define CONFIG_ENCODER_A_PIN        35
#define CONFIG_ENCODER_PUSH_PIN     27

/* Power */
#define CONFIG_POWER_EN_PIN         21
#define CONFIG_IMU_GPS_PWR_PIN      25
#define CONFIG_SCREEN_PWR_PIN       5

/* Debug USART */
#define CONFIG_DEBUG_SERIAL         Serial
#define CONFIG_DEBUG_RX_PIN         PA10
#define CONFIG_DEBUG_TX_PIN         PA9

/* SD CARD */
#define CONFIG_SD_SPI               SPI_SD
#define CONFIG_SD_CD_PIN            -1
#define CONFIG_SD_MOSI_PIN          PB15
#define CONFIG_SD_MISO_PIN          PB14
#define CONFIG_SD_SCK_PIN           PB13
#define CONFIG_SD_CS_PIN            15
#define CONFIG_SD_DET_PIN           22

/* Stack Info */
#define CONFIG_USE_STACK_INFO       0

#endif

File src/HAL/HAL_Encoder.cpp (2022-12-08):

#include "HAL/HAL.h"
#include "App/Utils/ButtonEvent/ButtonEvent.h"
// #include "App/Accounts/Account_Master.h"
#include "App/Common/DataProc/DataProc.h"

static ButtonEvent EncoderPush(5000,500,700);

static bool EncoderEnable = true;
static volatile int16_t EncoderDiff = 0;
static bool EncoderDiffDisable = false;

Account* actEncoder;

extern volatile bool isNormalMode;
extern volatile bool einkNeedUpdate;
// extern volatile bool isLcdOff;

static void Encoder_IrqHandler()
{
    // Serial.println("Encoder irq handle");
    if (!EncoderEnable || EncoderDiffDisable)
    {
        return;
    }
    // Serial.println("count");
    static volatile int count, countLast;
    static volatile uint8_t a0, b0;
    static volatile uint8_t ab0;
    uint8_t a = digitalRead(CONFIG_ENCODER_A_PIN);
    uint8_t b = digitalRead(CONFIG_ENCODER_B_PIN);
    if (a != a0)
    {
        a0 = a;
        if (b != b0)
        {
            b0 = b;
            count += ((a == b) ? 1 : -1);
            if ((a == b) != ab0)
            {
                count += ((a == b) ? 1 : -1);
            }
            ab0 = (a == b);
        }
    }

    if (count != countLast)
    {
        EncoderDiff += (count - countLast) > 0 ? 1 : -1;
        countLast = count;
    }
}

static void Encoder_PushHandler(ButtonEvent* btn, int event)
{
    if (event == ButtonEvent::EVENT_PRESSED)
    {
        // Serial.println("pressed");
        // HAL::Buzz_Tone(500, 20);
        EncoderDiffDisable = true;
    } else if (event == ButtonEvent::EVENT_RELEASED)
    {
        // Serial.println("released");
        // HAL::Buzz_Tone(700, 20);
        EncoderDiffDisable = false;
    }  else if (event == ButtonEvent::EVENT_DOUBLE_CLICKED)
    {
        Serial.println("button event double clicked");
        isNormalMode=!isNormalMode;
        einkNeedUpdate=true;
        // HAL::Buzz_Tone(700, 20);
        // EncoderDiffDisable = false;
    }  else if (event == ButtonEvent::EVENT_LONG_PRESSED)
    {
        Serial.println("button event long pressed");
        // HAL::Audio_PlayMusic("Shutdown");
        HAL::Power_Shutdown();
    }
}

static void Encoder_RotateHandler(int16_t diff)
{
    HAL::Buzz_Tone(300, 5);

    actEncoder->Commit((const void*) &diff, sizeof(int16_t));
    actEncoder->Publish();
}

void HAL::Encoder_Init()
{
    pinMode(CONFIG_ENCODER_A_PIN, INPUT_PULLUP);
    pinMode(CONFIG_ENCODER_B_PIN, INPUT_PULLUP);
    pinMode(CONFIG_ENCODER_PUSH_PIN, INPUT_PULLUP);

    attachInterrupt(CONFIG_ENCODER_A_PIN, Encoder_IrqHandler, CHANGE);

    EncoderPush.EventAttach(Encoder_PushHandler);
    Serial.println("encoder intr and event attached");

    actEncoder = new Account("Encoder", DataProc::Center(), sizeof(int16_t), nullptr);

}

void HAL::Encoder_Update()
{
    // if(Encoder_GetIsPush())
    //     Serial.println("is pushed");
    EncoderPush.EventMonitor(Encoder_GetIsPush());
}

int16_t HAL::Encoder_GetDiff()
{
    int16_t diff = -EncoderDiff / 2;
    if (diff != 0)
    {
        // EncoderDiff是实际的脉冲数；把本次变量用掉了，需要重新置0
        EncoderDiff = 0;
        Encoder_RotateHandler(diff);
    }

    return diff;
}

bool HAL::Encoder_GetIsPush()
{
    
    if (!EncoderEnable)
    {
        return false;
    }

    return (digitalRead(CONFIG_ENCODER_PUSH_PIN) == LOW);
}

void HAL::Encoder_SetEnable(bool en)
{
    EncoderEnable = en;
}

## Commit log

2022-06-29 include x-track pages
2022-10-04 Hardware design
    [Bike_Comp.PrjPCB, Button_FPC.SchLib, CTP_FPC.SchLib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]
2022-10-14 transfer to esp32-pico-kit
2022-10-21 Solar power
    [Bike_Comp.PrjPCB, Main.SchDoc, bp25504.SchLib]
2022-10-22 update power management
    [Main.SchDoc]
2022-10-24 add E-INK
    [EInk_FPC.SchLib]
2022-10-26 update pin map
    [Main.SchDoc]
2022-10-27 update pcbdoc
2022-10-28 net connect
    [Main.SchDoc]
2022-10-29 update eink error
    [Main.SchDoc]
2022-10-30 v2.2 finish
    [Main.SchDoc]
2022-10-31 hardware v2.3 fix power on logic
    [HAL_Power.cpp]
2022-10-31 hardware v2.3 fix power logic
    [Main.SchDoc]
2022-11-01 hardware v2.4
    [Bike_Comp v2.3.csv, Bike_Comp_v2.4.csv, Main.SchDoc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]
2022-11-02 hardware v2.6
    [Bike_Comp v2.3.csv, Bike_Comp_v2.4.csv, Bike_Comp_v2.5.csv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]
2022-11-03 hardware v2.7
    [Bike_Comp.PrjPCB, Bike_Comp_v2.5.csv, Bike_Comp_v2_6.csv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]
2022-11-09 Model upper case
    [shell v1.f3d]
2022-11-10 3d model v1.2
    [M_TRACK_V1_2.f3d, M_TRACK_v1_2.step, shell v1.f3d]
2022-11-11 model v1.3
    [M_TRACK_V1_2.f3d, M_TRACK_v1_2.step, M_Track_v1_3.stl]
2022-11-18 adapt for PCB
2022-11-19 PCB LCD work
2022-11-21 3D model v1.4
    [M_Track_back_v1_4.stl, M_Track_front_v1_4.stl, M_Track_v1_3.stl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]
2022-11-22 hardware v2.7 rev1
    [Main.SchDoc]
2022-11-22 encoder enabled
2022-11-28 solve settings focus problem
    [Settings.cpp, SystemInfos.cpp]
2022-12-02 pressing logic of mode switch
2022-12-02 press logic of mode switch
2022-12-02 fix encoder double click logic
    [Config.h, HAL_Encoder.cpp, lv_port_indev.cpp]
2022-12-05 poster stuff, switches and GPS enable
2022-12-06 Map loaded, locationing drift
    [Config.h, HAL.cpp, HAL_SdCard.cpp]
2022-12-06 fix time, time zone, gpx create but not recorded
    [Config.h, Dialplate.cpp, HAL_GPS.cpp]

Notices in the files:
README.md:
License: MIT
